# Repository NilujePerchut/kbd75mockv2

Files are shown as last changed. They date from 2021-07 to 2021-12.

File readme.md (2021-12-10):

# KBD75mockV2

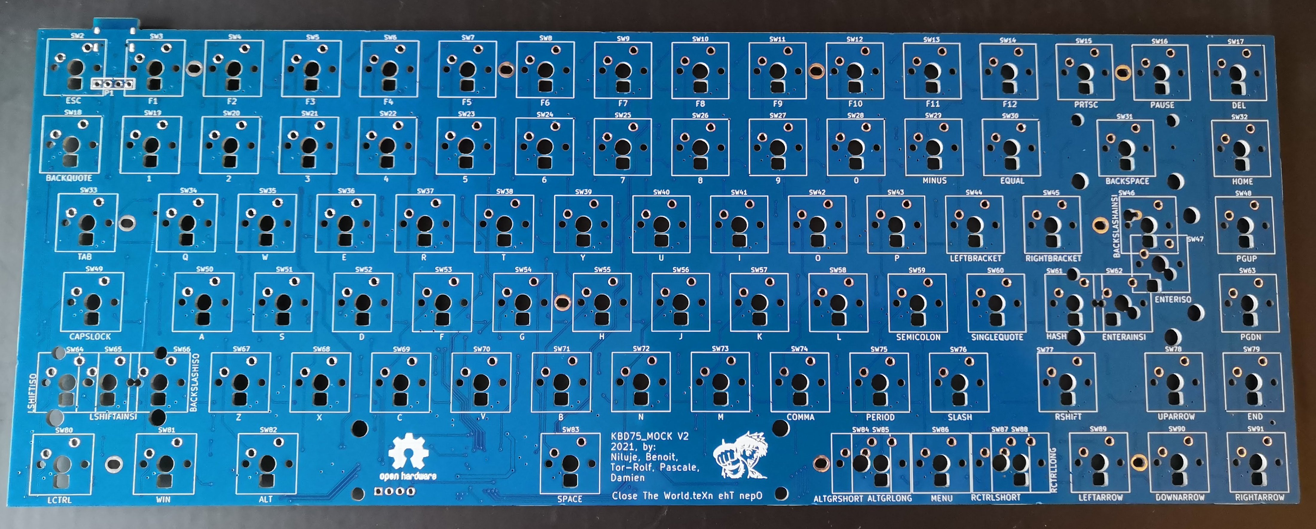
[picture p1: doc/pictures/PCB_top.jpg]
The PCB


An open-source KBD75V2 alternative PCB with the following features:
- STM32F103 microcontroller
- Per-Key RGB backlight (SK6812MINI-E)
- 16 RGB backlight LEDs (compatible with offical foam hole location)
- USB-C connector
- AINSI & ISO layouts
- Alternate layout for spacebar right side keys
- Mechanicaly compatible with the KBDFans KBD75V2 case
- Also compatible with the YMDK84 case (tested with acrylic case)
- QMK compatible (see [qmk firmware support](https://github.com/NilujePerchut/qmk_firmware/tree/kbd75mockv2))
- JLCPCB friendly workflow:
    - Complies with JLCPCB design rules
    - Uses component available at JLCPCB SMT part

## Disclamers
I am not affiliated in any way with the KBDFans corporation. This is NOT a KBDFans product.

This design comes with no warranty at all. See LICENSE file for more details.

# Status
Rev A0 prototype assembled and functionnal.
See Bug section below for more details.

## RevA0 Bugs
- Some fixing holes are not aligned with official KBD75V2 case inserts.
- Missing one RGB backlight led on each lateral side. This creates a hole in the surrounding ring.

## Usage

Be sure to understand the [Status](#status) and [Bugs](reva0-bugs) sections before investing money in such project.

```
git clone --recurse-submodules https://github.com/NilujePerchut/kbd75mockv2
```
_Note:_ This project uses [skidl](https://github.com/devbisme/skidl) to produce a netlist instead of using a regular schematics editor. It also relies on some automatic routing via python scripts for repetitive placement and routing tasks. The PCB is then completed by hand using kicad's pcbnew.

### PCB manufaturing & assembly
Open the [Routed PCB](hard/pcb/final_pcb/kbd75mock_v2_routed.kicad_pcb) with kicad and generate the GERBER files.

All relevant footprints have a _JLCC_ field with JLCPCB SMT command code. This can be used to generate JLCPCB assembly request.

### Configuration
If you need the per-key RGB backlight feature, make a solder joint between pins 1 and 2 of P3.

### QMK firmware

All related files are located in the [qmk_firmware](qmk_firmware) directory.

The compilation and flashing steps use the convenient `qmk` cli tool provided by qmk_firmware. See [QMK cli](https://docs.qmk.fm/#/cli) for more details. 

## Bootloader installation
This board uses the standard stm32duino bootloader. The SWD P2 connector to flash it using your prefered method (tested with an STLINKV2 clone).

## Compilation
```
cd qmk_firmware
qmk compile -km default -kb kbd75mockv2
```

## Flashing
```
qmk flash -km default -kb kbd75mockv2
```

_WARNING_: Default RGB MATRIX (per key LEDs) max brightness is set to 0x100. This value causes the whole PCB (including RGB backlight) to drain around 400mA on the USB bus.This represents more than 2W of power consumption and clearly heats the whole structure. You might want to lower this value to lower heat dissipation.

## RevA1 TODO
- [ ] Rework PCB routing to enhance performances
- [ ] Fix location of mechanical fixing holes
- [ ] Move backlight RGB LEDs to be compliant with official foam
- [ ] Add one more RGB backlight LED one each lateral side
- [ ] (if possible) Add split backspace option
- [ ] (if possible) Add alternate tab key option
- [ ] (if possible) Add split spacebar option

## Galerie

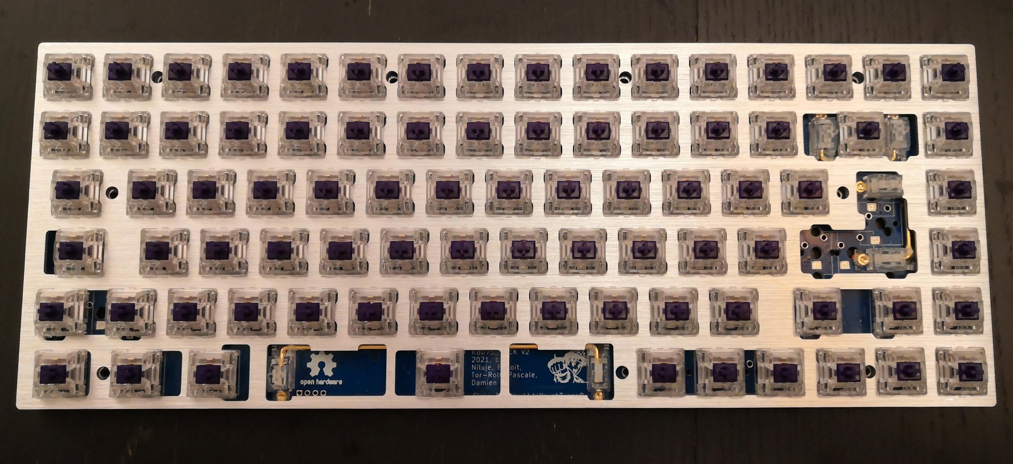
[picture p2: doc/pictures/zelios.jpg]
KBD75V2 Plate


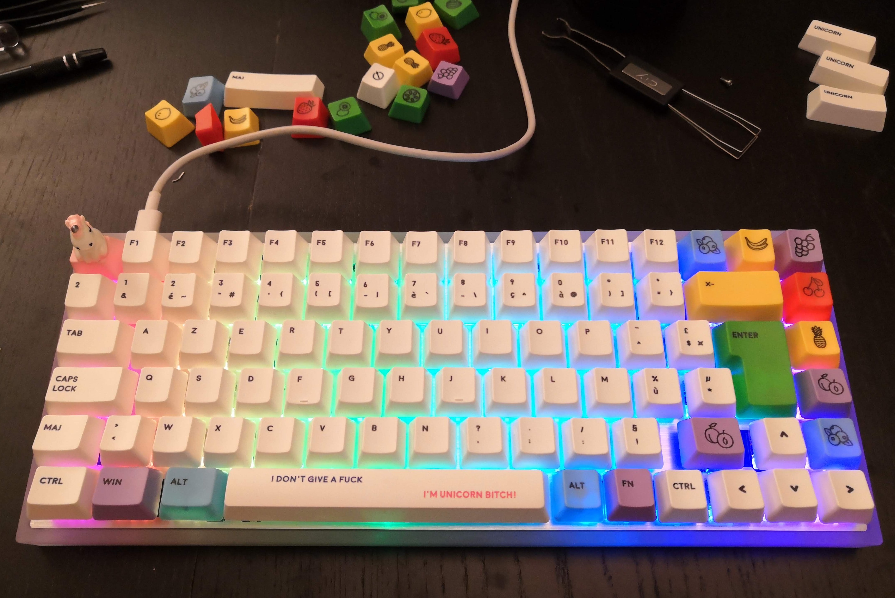
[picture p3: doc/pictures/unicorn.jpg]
YMDK84 case


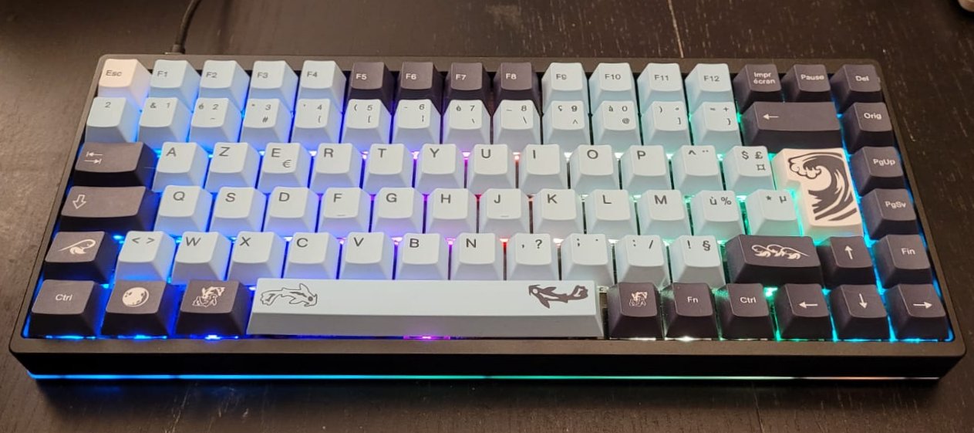
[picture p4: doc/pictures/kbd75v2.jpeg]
KBD75V2 case


## Credits & Thanks
- Benoit, Tor-Rolf, Damien & Pascale for the precious help
- [KBDFans](https://kbdfans.com/)
- [QMK](https://qmk.fm/)
- [SKIDL](https://github.com/devbisme/skidl)
- [Kicad]

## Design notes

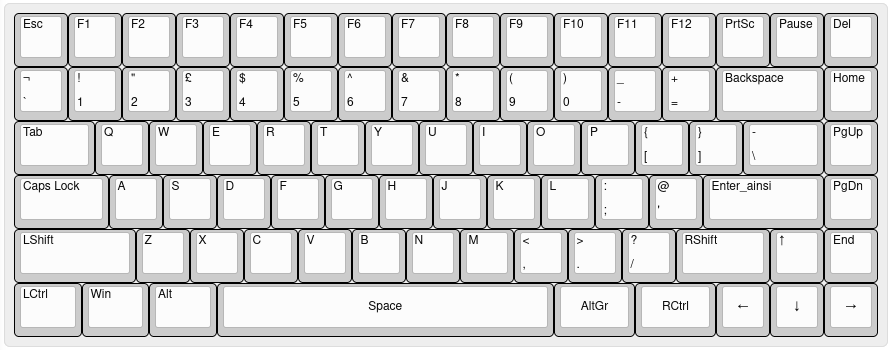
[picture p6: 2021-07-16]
doc/ainsi.png

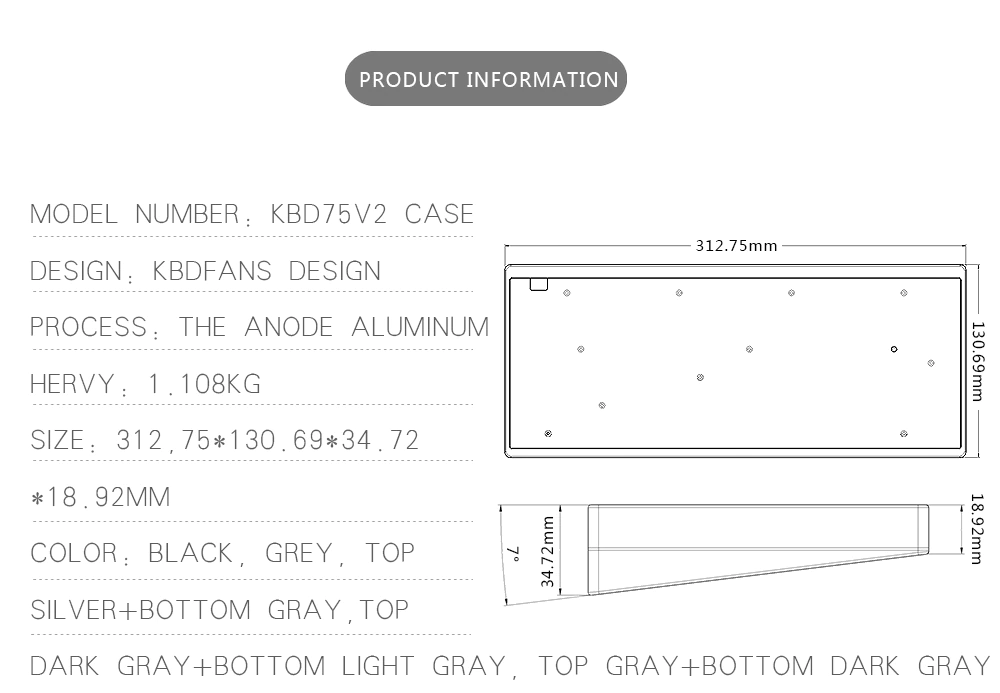
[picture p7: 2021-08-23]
doc/references/H3bfeb22f4393418a8da06734db001d4c2.webp

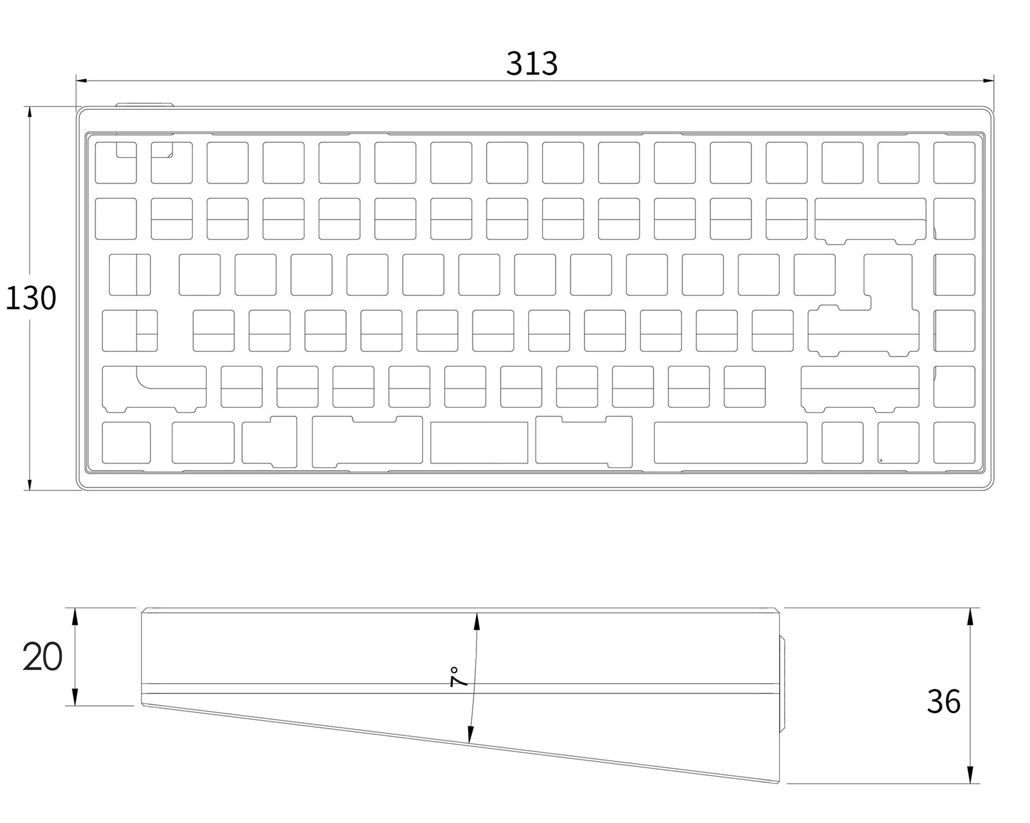
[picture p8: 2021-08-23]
doc/references/20210529150432_2048x2048.webp

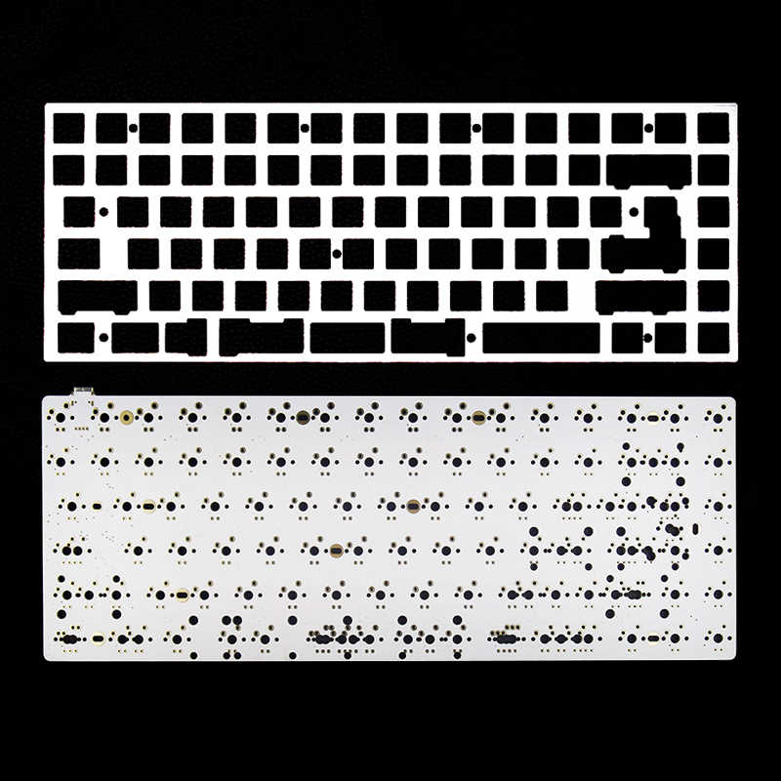
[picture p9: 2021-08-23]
doc/references/KBD75-REV-2-0-PCB-TYPE-C-USB-kbd75-plaque-de-circuit-imprim-plaque-alu.jpg_q50.jpg

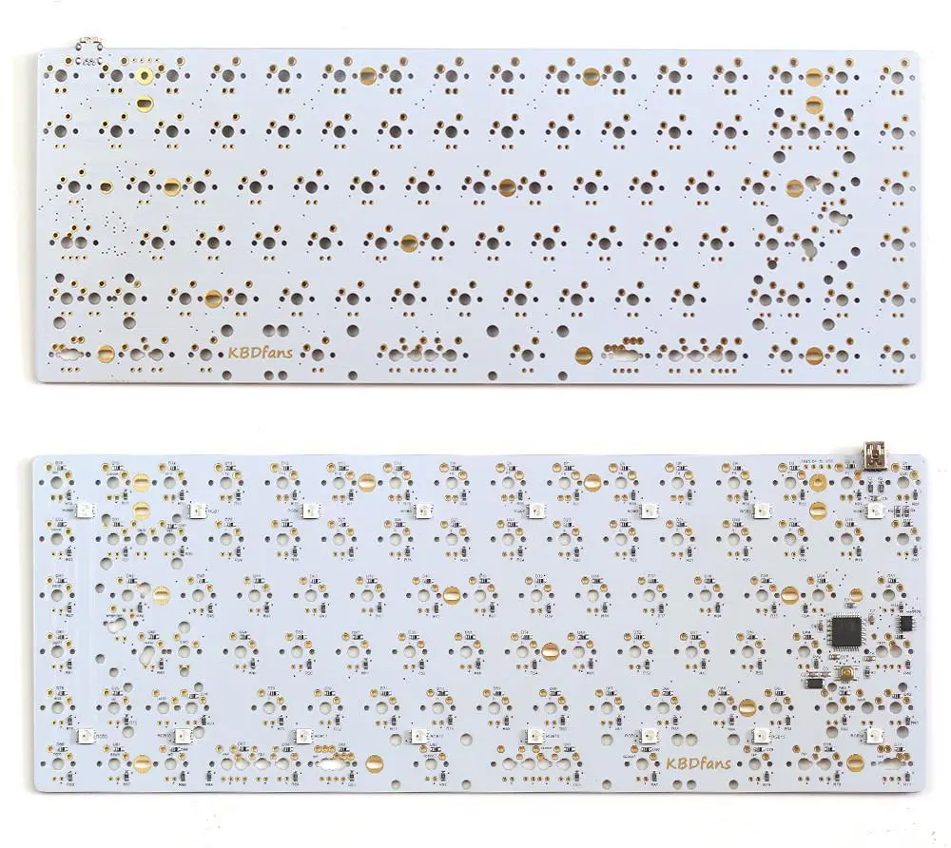
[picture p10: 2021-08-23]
doc/kbd75rev2-PCB.webp

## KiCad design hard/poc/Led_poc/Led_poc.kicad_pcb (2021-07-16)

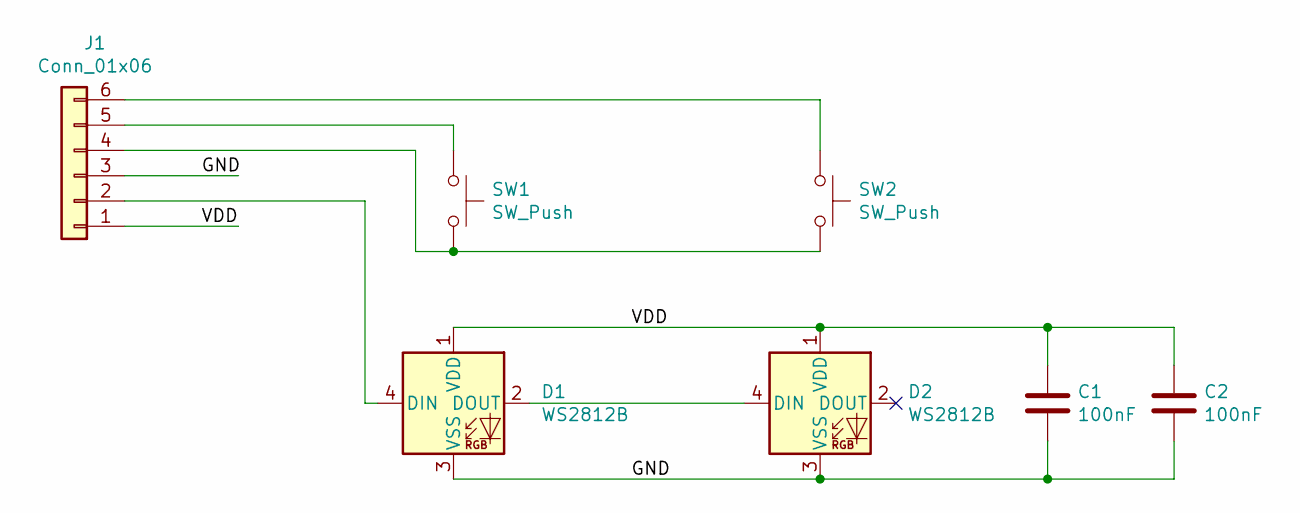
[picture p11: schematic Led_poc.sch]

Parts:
C1, C2: 100nF; C_0201_0603Metric_Pad0.64x0.40mm_HandSolder
D1, D2: WS2812B; SK6812
J1: Conn_01x06; PinHeader_1x06_P2.54mm_Vertical
SW1, SW2: SW_Push; SW_Cherry_MX_1.00u_PCB

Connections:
/GND: C1.2, C2.2, D1.3 (VSS), D2.3 (VSS), J1.3
/VDD: C1.1, C2.1, D1.1 (VDD), D2.1 (VDD), J1.1
unnamed: D1.2 (DOUT), D2.4 (DIN)
unnamed: D1.4 (DIN), J1.2
unnamed: J1.4, SW1.2, SW2.2
unnamed: J1.5, SW1.1
unnamed: J1.6, SW2.1

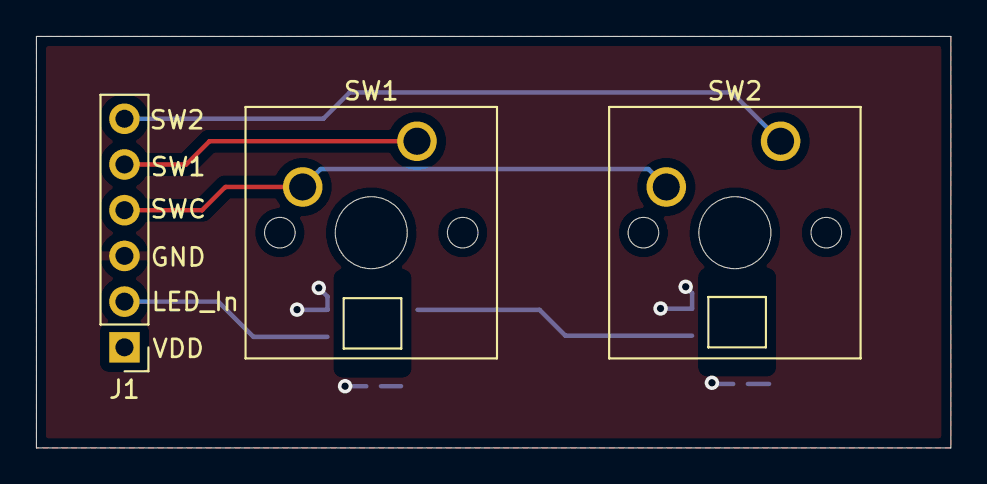
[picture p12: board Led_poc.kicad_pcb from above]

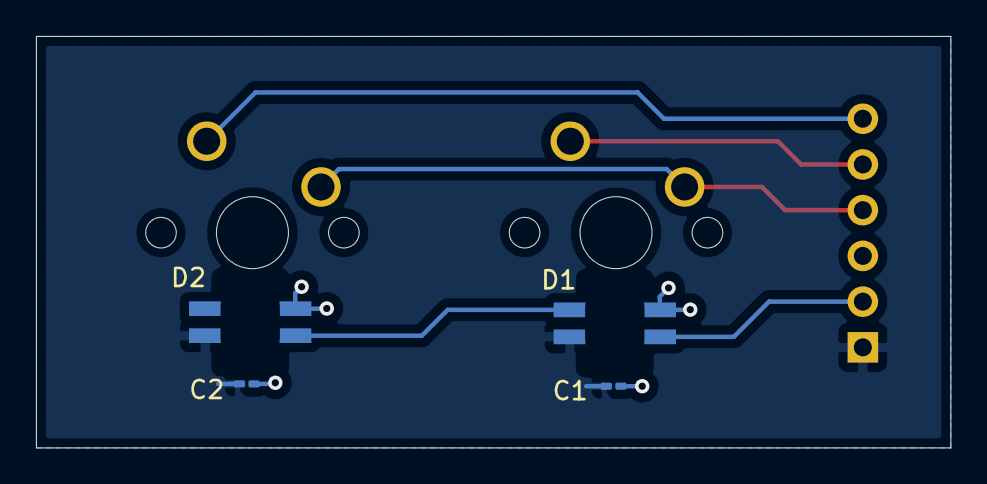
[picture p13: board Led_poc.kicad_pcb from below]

Board: 2 copper layers, 50.8 x 22.9 mm, 7 parts (4 on the bottom side), 7 nets.

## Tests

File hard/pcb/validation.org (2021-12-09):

#+TITLE: KBD75mockV2 validation

* Mechanical
** Backlight LED placement
*** Top row [1/1]
- [X] Placement is ok (more or less)

*** Bottom row [/]
Starting from USB side: 4, 6, 7 are miss-placed
- [ ] 4 is one LED too far on rigth (bottom view)
- [ ] 6 is 1/2 LED too far on right (bottom view)
- [ ] 7 is one LED too far on rigth (bottom view)
** Per-key LED [1/1]
- [X] Hole size: OK
** Mounting screws [0/0]
*** Top row [1/1]
- [X] Placement
*** Third row [1/3]
- [ ] First is 2mm too much on left
- [ ] 2 & 3 missing for kbd75v2 case
- [X] Fourth is OK
*** Third and a half row [0/1]
- [ ] missing for kbd75V2 case
*** Fouth row [1/1]
- [X] placement ok
*** Sixth row [1/4]
- [ ] First 2mm too much on left
- [ ] Second is missing for YMD case
- [ ] Third 2mm too much on left
- [X] Forth is ok
** USB connecter [3/3]
- [X] Placement OK
- [X] USB cable space for YMD case
  Need to push the PCB on the right
- [X] USB cable space for KBD75V2 case
  Perfect

* Electrical
** Missing component [1/1]
- [X] C1 is missing 100nF 0603
** Power options [2/3]
- [X] From USB C
- [X] From USB C reverse
- [ ] From P1
** 5V power
OK mesured at P1 (also OK with USB reversed)
** 3.3V power
OK mesured at P2 (also OK with USB C reversed)
** Oscillator
8MHz on oscillator pin 3
** STM32 bringup
- [X] SWD
- [X] USB connection
- [X] Programming
- [X] QMK detected from PC
** Key matrix
- All key detected [4/4]
  - [X] ISO layout
  - [X] AINSI layout
  - [X] 3 1U bottom right row
  - [X] 2 1.5U bottom right row
** LED backlight
- [X] Standalone (OK at MAX brightness)
  OK for cutom RGBLIGHT driver.
- [ ] Chained (not needed)
** Per-key LED
- [X] Max brightness

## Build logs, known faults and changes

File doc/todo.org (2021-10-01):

#+TITLE: KBD75 Mock TODO

* Features [2/3]
- [X] Add a SIL4 for external USB connection
- [ ] Add GPLV3 header on each files
- [X] Add Licence file
- [ ] Use git submodule for kicad_libs

* Netlist [10/10]
- [X] Generate a JSON file with unique keys and a duplicate dict
- [X] Add some capas (tank+100nF) capas
- [X] Switch backlight LED to 5050 format
- [X] Add passive component value to netlist
- [X] Re-think the external USB connection
- [X] Invert USB-P and USB-N on usb filter + SIL4
- [X] Add 3d models for each footprint (not needed)
- [X] Re-attribute cols and rows
    |-----+-----------------------+-----------------------+---------|
    | Pin | Original Net          | New Net               | New Pin |
    |-----+-----------------------+-----------------------+---------|
    |  13 |                       | COL_7                 | PA3     |
    |  14 |                       | COL_8                 | PA4     |
    |  15 |                       | COL_10                | PA5     |
    |  16 |                       | COL_9                 | PA6     |
    |  26 | COL_0                 | ROW_5                 | PB13    |
    |  27 | COL_1                 | COL_0                 | PB14    |
    |  28 | COL_2                 | COL_1                 | PB15    |
    |  29 | COL_3                 | COL_3 (idem)          | PA8     |
    |  31 | COL_4                 | COL_2                 | PA10    |
    |  18 | COL_5                 | COL_12                | PB0     |
    |  17 | COL_6                 | COL_11                | PA7     |
    |  38 | COL_7                 |                       |         |
    |  39 | COL_8                 |                       |         |
    |  40 | COL_9                 | BACKLIGHT_LED_COMMAND | PB4     |
    |  41 | COL_10                | CAPS_LOCS_LED_CMD     | PB5     |
    |  43 | COL_11                | ROW_3                 | PB7     |
    |  45 | COL_12                | ROW_2                 | PB8     |
    |  46 | COL_13                | COL_5                 | PB9     |
    |  11 | COL_14                | ROW_1                 | PA1     |
    |  42 | ROW_0                 |                       |         |
    |  30 | ROW_1                 | COL_4                 | PA9     |
    |  25 | ROW_2                 | PER_KEY_LED_CMD       | PB12    |
    |  22 | ROW_3                 |                       |         |
    |  21 | ROW_4                 | COL_14                | PB10    |
    |  19 | ROW_5                 | COL_13                | PB1     |
    |   2 | CAPS_LOCK_LED_CMD     | ROW_4                 | PC13    |
    |  10 | PER_KEY_LED_CMD       | ROW_0                 | PA0     |
    |  12 | BACKLIGHT_LED_COMMAND | COL_6                 | PA2     |
    |-----+-----------------------+-----------------------+---------|
- [X] Check inductor JLCPCB ref
- [X] Add backlight leds JLCPCB package

* PCB
** Key modules modifications [3/3]
- [X] Invert Space key stabs holes
- [X] Add mechanics
  - [X] Screw holes
  - [X] JLCPCB fiducials
  - [X] JLCPCB tooling holes
  - [X] SAKURA
- [X] Adjust Screw holes

** Footprints [3/3]
- [X] decal backslash_ainsi switch pcb hole to allow soldering
- [X] Enlarge Sakura Mask
- [X] Use Sakara Mask on bottom too => Cancel

** Placement [10/10]
- [X] Place all key switch footprint using the data
- [X] Gather switch, LED, capa, diode in one python structure to ease the data retrival
- [X] Per key LEDs
  - [X] Place per key LED
  - [X] Only use one LED for both AltGr and RightCtrl
  - [X] Adjust designator (rotation, avoid hole)
- [X] Place LED (backlight)
- [X] Place LED capa (no one capa per led but just a bunch of capa) => No capa
- [X] Place key diode
- [X] Place the USB connector
- [X] Place the STM32
- [X] Set Switches values not visible
- [X] Check the usb c connector location against the actual case

** Routing [5/5]
- [X] Creates signal classes
  - [X] Setup trace widths
- [X] Creates outline
- [X] Add plate outline (no need)
- [X] Add case dimensions (to place USB connector correctly)
- [X] Use correct power track width to allow routing in small space

** Manfucturing [5/5]
- [X] Generate BOM
- [X] Generate Gerbers
- [X] Generate Drill Files (Excellon + Drill map)
- [X] Generate Assembly file
- [X] Generate JLCPCB placement file

** MISC
- [X] Set the PCB to 4 layers (compare with Doppleganger PCB) => Not needed, Thanks to Tor-Rolf
- [X] Set the pcb size to A3
- [X] Adds Copyrights on Top Silks (spacebar right part)

* Software
** Minimal ISO keyboard [0/1]
- [ ] Use git submodule for qmk firmware
- [ ] Create new keyboard
- [ ] Create niluje-iso keymap
** Implements layers
** Add AINSI keymap
** Add VIA support
** Add Perkey backlight
** Add backlight

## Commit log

2021-07-16 Switches to more classical infra
    [Led_poc-B_Cu.gbl, Led_poc-B_Mask.gbs, Led_poc-B_Paste.gbp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]
2021-07-23 STM32 first version
2021-08-01 STM32 + unit test
2021-08-01 Regulator + unit test
2021-08-01 Refactor leds to include bakclight
2021-08-01 Updates TODO with post schematics tasks
2021-08-06 Move per key led chain start at bottom left
2021-08-06 Switch backlight LEDs to 5050 WS2812B
2021-08-08 Reverser Stab holes for space bar
2021-08-08 Update Mech with fix holes and update final keyboard
2021-08-08 Add documentation about mounting types
2021-08-08 Move/Rotate the LED designator to avoid switch hole
2021-08-08 Allow LED chain alternate command
2021-08-09 Place Backlight LEDs
2021-08-19 Use dedicated ainsi backslash footprint with enlarged #1 pad
2021-08-30 Add routing script with edge cut
2021-08-31 Add diode anonde routing
2021-09-01 Add GND and V5V planes
2021-09-05 Place via on LEDs GND
2021-09-05 Route LED links
2021-09-11 Add YMDK case + placement
2021-09-11 Defines Power netclass
2021-09-16 Adjust LEDs GND vias distance
2021-09-16 Suppress 45° in LED chain routing
2021-10-01 Fix voltage for general bypass capacitor
    3.3V to 5V
2021-10-01 Add JLCPCB code for backlight RGB diodes
2021-10-01 Change power Ferrite
2021-10-01 Update STM32 pinout to ease the routing process
2021-10-01 Add jlcpcb assembly makefile target
2021-10-01 Add final PCB
2021-10-03 Add kicad_libs from submodule
